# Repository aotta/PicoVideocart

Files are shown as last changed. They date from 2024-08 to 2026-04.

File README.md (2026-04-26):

# PicoVideocart

changelog: v.1.1 added with new Adafruit USB stack

Flash cart for SABA Videoplay - porting of 3DMaze PicoVideocart

This is a forked version of https://github.com/ZX-80/PicoVideocart (see original project for details) for using a cheaper and simpler pcb based on pico "Purple" clone and using its 16mb flash for storing games instead of the original SDCard

Since now it was only tested on SABA Videoplay (PAL), but it should work in Fairchild Channel-F (NTSC) too.

Thanks to my friend Dave, here's some more info and the label for the shell:
https://www.nightfallcrew.com/05/09/2024/flash-multicart-for-saba-videoplay-fairchild-channel-f/

**WARNING!** "purple" Pico has not the same pinout of original Raspberry "green" ones, you MUST use the clone or you may damage your hardware.

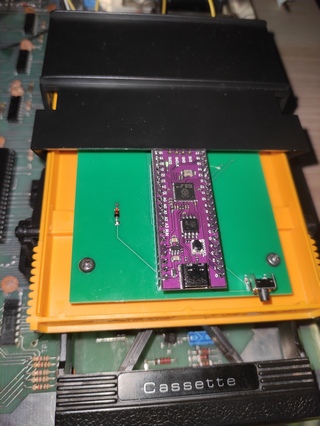
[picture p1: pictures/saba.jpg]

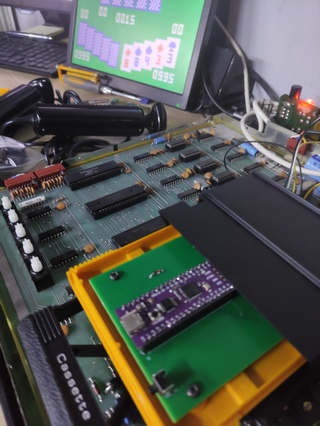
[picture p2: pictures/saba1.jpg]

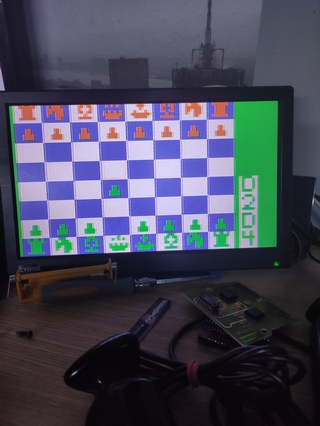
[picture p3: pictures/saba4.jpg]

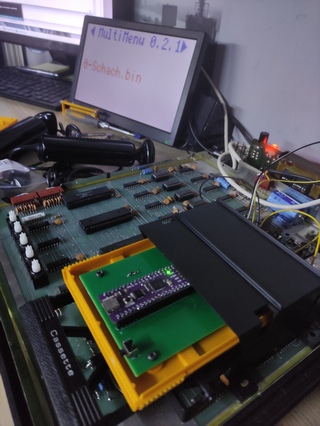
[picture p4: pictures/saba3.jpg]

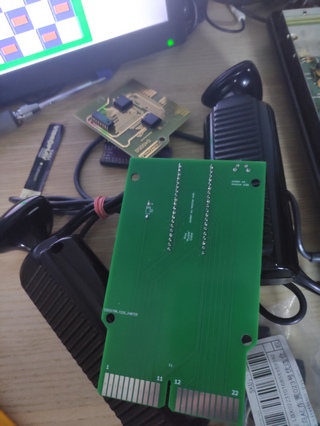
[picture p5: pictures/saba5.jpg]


Kicad project and gerbers files for the pcb are in the PCB folder, you need only a diode and a push buttons for resetting the cart if needed or want restart. 
Add you pico clone, and flash the firmware ".uf2" in the Pico by connecting it while pressing button on Pico and drop it in the opened windows on PC.

in V.1.0, "Bin" files should be added in flash using Arduino IDE plugin ( https://github.com/earlephilhower/arduino-littlefs-upload )
be sure to put boot.bin with other games, it's the menu selector.

**NOTE: V.1.1 use now Adafruit stack USB and you can upload bin files by connecting the card to a PC via usb cable and copying them on the flash folder. First time flash folder need to be formatted as FAT disk.
Now the multicart check at boot if it's inserted in console, if you get flashing led at boot, reset Picovideocart or powercycle the console until you get a steady flash led.

More info on AtariAge forum: https://forums.atariage.com/topic/274416-the-official-channel-f-thread/page/56/

Even if the diode should protect your console, **DO NOT CONNECT PICO WHILE INSERTED IN A POWERED ON CONSOLE!**

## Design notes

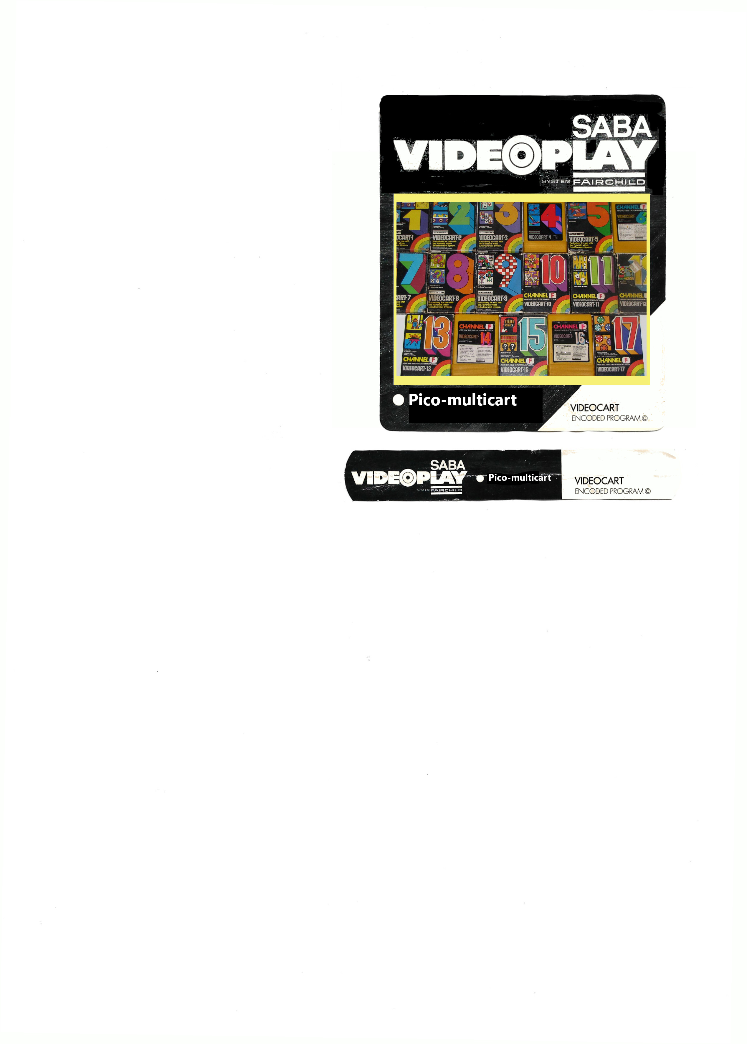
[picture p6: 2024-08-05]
pictures/ShellLabel.jpg

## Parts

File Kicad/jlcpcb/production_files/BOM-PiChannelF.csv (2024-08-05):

Comment | Designator | Footprint | LCSC
ChannelF Edge | E1 | ChannelF_EDGE
Diode | D1 | D_DO-35_SOD27_P7.62mm_Horizontal
Conn_01x20 | J1 | PinSocket_1x20_P2.54mm_Vertical
SW_Push | SW1 | SW_Tactile_SPST_Angled_PTS645Vx58-2LFS
Conn_01x20 | J2 | PinSocket_1x20_P2.54mm_Vertical
330 | R1 | R_Axial_DIN0207_L6.3mm_D2.5mm_P7.62mm_Horizontal
LED | D2 | LED_D3.0mm

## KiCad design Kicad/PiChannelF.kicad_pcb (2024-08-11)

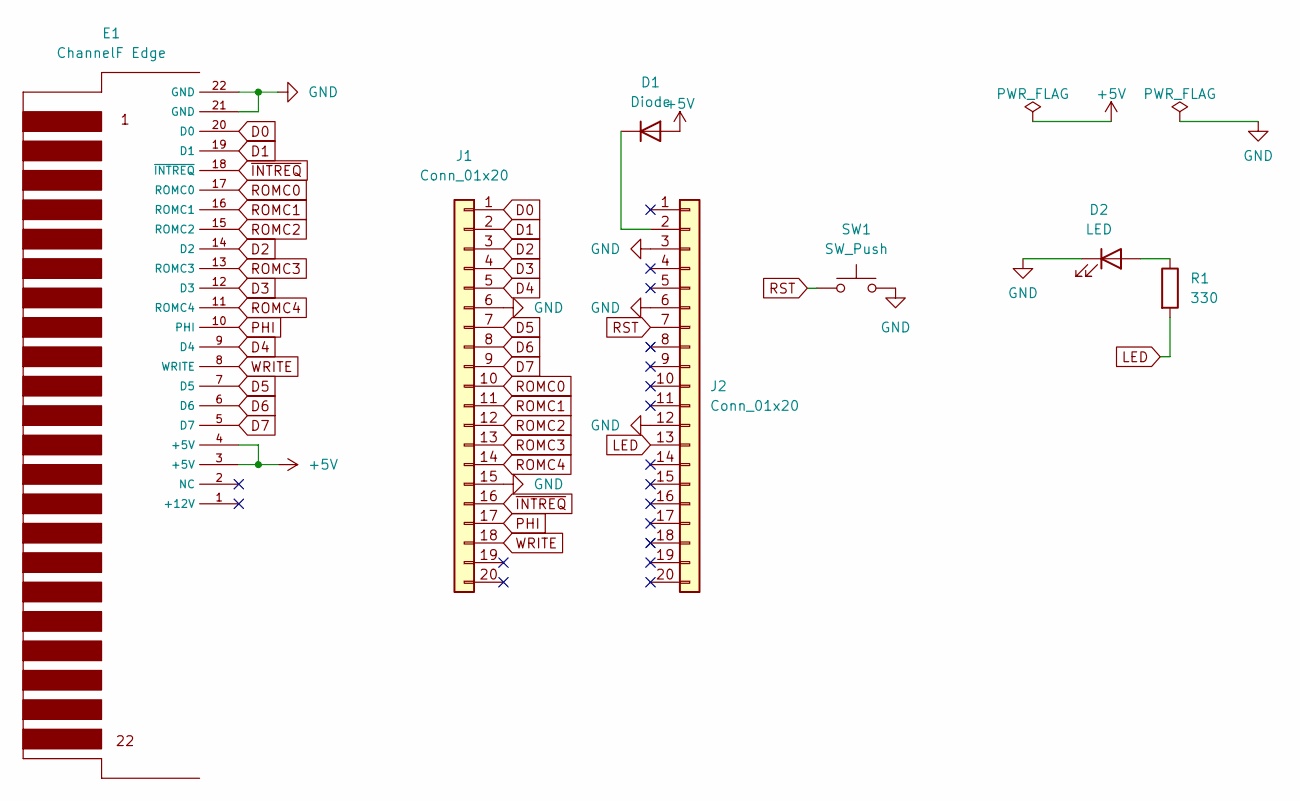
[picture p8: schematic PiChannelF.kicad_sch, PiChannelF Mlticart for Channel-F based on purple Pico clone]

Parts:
D1: Diode; D_DO-35_SOD27_P7.62mm_Horizontal
D2: LED; LED_D3.0mm
E1: ChannelF Edge; ChannelF_EDGE
J1, J2: Conn_01x20; PinSocket_1x20_P2.54mm_Vertical
R1: 330; R_Axial_DIN0207_L6.3mm_D2.5mm_P7.62mm_Horizontal
SW1: SW_Push; SW_Tactile_SPST_Angled_PTS645Vx58-2LFS

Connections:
+5V: D1.2 (A), E1.3 (+5V), E1.4 (+5V)
D0: E1.20 (D0), J1.1
D1: E1.19 (D1), J1.2
D2: E1.14 (D2), J1.3
D3: E1.12 (D3), J1.4
D4: E1.9 (D4), J1.5
D5: E1.7 (D5), J1.7
D6: E1.6 (D6), J1.8
D7: E1.5 (D7), J1.9
GND: D2.1 (K), E1.21 (GND), E1.22 (GND), J1.6, J1.15, J2.3, J2.6, J2.12, SW1.2
LED: J2.13, R1.2
unnamed: D1.1 (K), J2.2
unnamed: D2.2 (A), R1.1
PHI: E1.10 (PHI), J1.17
ROMC0: E1.17 (ROMC0), J1.10
ROMC1: E1.16 (ROMC1), J1.11
ROMC2: E1.15 (ROMC2), J1.12
ROMC3: E1.13 (ROMC3), J1.13
ROMC4: E1.11 (ROMC4), J1.14
RST: J2.7, SW1.1
WRITE: E1.8 (WRITE), J1.18
~INTREQ: E1.18 (~INTREQ), J1.16

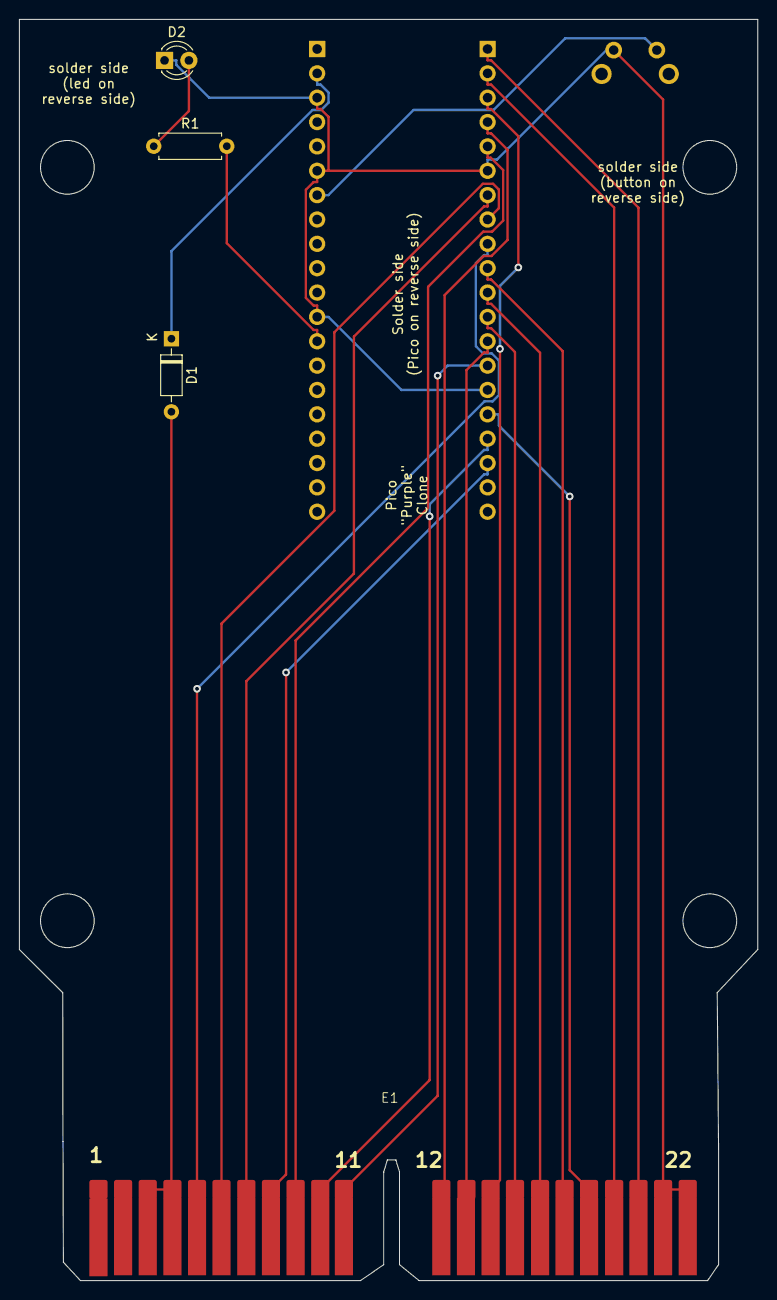
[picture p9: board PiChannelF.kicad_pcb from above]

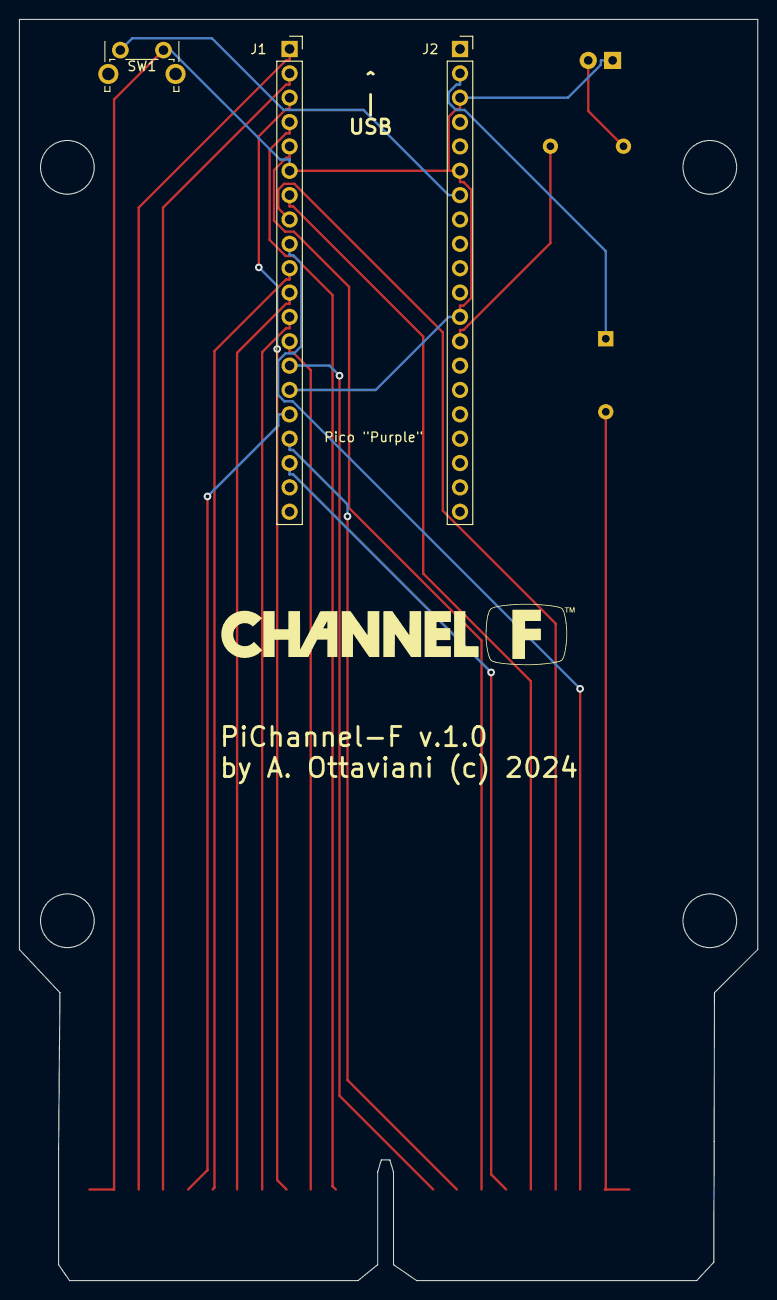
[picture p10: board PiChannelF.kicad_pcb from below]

Board: 2 copper layers, 77.0 x 131.5 mm, 7 parts (3 on the bottom side), 22 nets.

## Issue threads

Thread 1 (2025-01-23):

HD not recogniuing after flashing firmware and cartrdidge uf2

G7200, 2025-01-23:
Hi, I try to flash my Pico for the PicoVideocart. I followed your and Nightfallcrew's instructions and used Nightfallcrew's files for flashing the Pico. I flashed the cartridges first and then the firmware uf2 file as he told on his website. After that the Pico does not appear anymore on my PC via USB cable. Is that normal?
I have not understood yet how to put my own bin files to the Pico as I have no Arduino.
Thanks for your help!

aotta, 2025-01-23:
Yes it's normal, the only way for uploading rom filles is via the LittleFS plugin and Arduino IDE, follow instructions in the link in readme.md of this project

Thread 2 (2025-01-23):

Cart not recognized

G7200, 2025-01-23:
Hi,
I just did the Arduino part and compiled the firmware on the cart. After inserting the cart into my Saba Videoplay all I get is 3x4 red led flashes and after that always a non-flashing red light but nothing on the screen.
It is not very clear written what to flash first and how exactly. Normally the firmware is flashed by pushing the reset button and then the game files by just plugging in the USB without pushing reset on the pico.

aotta, 2025-01-23:
You MUST FIRST flash the pico with uf2 provided, THEN upload the bin file with littlefs upload.
It's clearly written in the readme.md:
`Add you pico clone, and flash the firmware ".uf2" in the Pico by connecting it while pressing button on Pico and drop it in the opened windows on PC. "Bin" files should be added in flash using Arduino IDE plugin ( https://github.com/earlephilhower/arduino-littlefs-upload )`

Please note that this section is for issue in the project, not a forum for discussing or user support.  You may use the mentioned thread in AtariAge forum for them.

G7200, 2025-01-24:
Hi Andrea,
Sorry for bothering you again.
The steps aren't really clear for me especially not for someone like me who
never used Arduino before.

I could now successfully upload the .bin files with the arduino
littlefs-upload plugin.

Is the firmware uf2 file you provided inside the arduino build folder from
your github?

Can this be flashed normally without arduino by just pressing the pico
button and copied over into the pico directory?

Thanks and all the best from Bern,
;) Balduin

Andrea Ottaviani ***@***.***> schrieb am Do., 23. Jan. 2025,
17:35:

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

aotta, 2025-01-24:
Hi Balduin, yes the steps are, strictly in this order:
1. Connect Pico to pc while pushing boot button
2. Flash Pico copying the uf2 file in build folder into the pico flash folder, as usual
3. Load games via littleFs plugin
4. Enjoy the carts

G7200, 2025-01-24:
Hi Andrea!
Thanks for replying again.
Are the two boot.bin (and old) files necessary and need to be in the data
folder?
For littlefs-upload I always use your PicoVideocart.ino sketch folder.

I hope I will get it working soon!

Thanks and all the best,
;) Balduin

Andrea Ottaviani ***@***.***> schrieb am Fr., 24. Jan. 2025,
13:53:

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

aotta, 2025-01-24:
Right, i missed mention but boot.bin must be uploaded with other games bin files.
You can use any sketch in background when using littlefs upload, but check that pico parameters are the right one, in particular the flash size must be set to 1mb/15 mb

G7200, 2025-01-24:
3. Step-Question: Do I need to press button on Pico to upload games via
littleFS plugin?
Because I cannot see the COM port after flashing the provided uf2 firmware
when pushing button on Pico.

All the best!

Am Fr., 24. Jan. 2025 um 13:53 Uhr schrieb Andrea Ottaviani <
***@***.***>:

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

Closed 2025-01-23.

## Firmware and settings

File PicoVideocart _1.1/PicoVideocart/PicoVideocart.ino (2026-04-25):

/* \file PicoVideocart.ino
 */
// V.1.1  moved from LittleFS to Adafruit USB Stack

#include "loader.hpp"
#include "error.hpp"
#include "romc.hpp"
#include "pico/stdlib.h"
#include "hardware/adc.h"
#include "hardware/flash.h"
#include "hardware/vreg.h"
#include "hardware/structs/bus_ctrl.h"
#include "SdFat_Adafruit_Fork.h"
#include "Adafruit_SPIFlash.h"
#include "Adafruit_TinyUSB.h"

Adafruit_FlashTransport_RP2040 flashTransport;
Adafruit_SPIFlash flash(&flashTransport);

FatVolume fatfs;
File32 root;
File32 file;
File32 romFile;

Adafruit_USBD_MSC usb_msc;
bool fs_formatted;
bool fs_changed = false;

// Pin definitions
#define D0_PIN     0
#define D1_PIN     1
#define D2_PIN     2
#define D3_PIN     3
#define D4_PIN     4
#define D5_PIN     5
#define D6_PIN     6
#define D7_PIN     7
#define ROMC0_PIN  8
#define ROMC1_PIN  9
#define ROMC2_PIN 10
#define ROMC3_PIN 11
#define ROMC4_PIN 12
#define INTREQ_PIN 13
#define PHI_PIN    14
#define WRITE_PIN  15

#define DATA_PIN_MASK   0x000000FFL
#define SET_DATA_MODE_OUT   gpio_set_dir_out_masked(DATA_PIN_MASK)
#define SET_DATA_MODE_IN    gpio_set_dir_in_masked(DATA_PIN_MASK)

// Callbacks USB MSC
int32_t msc_read_cb(uint32_t lba, void* buffer, uint32_t bufsize) {
  return flash.readBlocks(lba, (uint8_t*)buffer, bufsize / 512) ? bufsize : -1;
}

int32_t msc_write_cb(uint32_t lba, uint8_t* buffer, uint32_t bufsize) {
  return flash.writeBlocks(lba, buffer, bufsize / 512) ? bufsize : -1;
}

void msc_flush_cb(void) {
  flash.syncBlocks();
  fatfs.cacheClear();
  fs_changed = true;
}


void setup1() {
  bus_ctrl_hw->priority = BUSCTRL_BUS_PRIORITY_PROC1_BITS;
  
  for (int i = 0; i < 8; i++) {
    gpio_set_function(D0_PIN + i, GPIO_FUNC_SIO);
  }
  for (int i = 0; i < 5; i++) {
    gpio_set_function(ROMC0_PIN + i, GPIO_FUNC_SIO);
  }
  
  gpio_init(WRITE_PIN);
  gpio_set_dir(WRITE_PIN, GPIO_IN);
  gpio_init(PHI_PIN);
  gpio_set_dir(PHI_PIN, GPIO_IN);
  gpio_init(INTREQ_PIN);
  gpio_set_dir(INTREQ_PIN, GPIO_OUT);
  gpio_put(INTREQ_PIN, true);
  gpio_init(LED_BUILTIN);
  gpio_set_dir(LED_BUILTIN, GPIO_OUT);
  gpio_put(LED_BUILTIN, true);
}

void __not_in_flash_func(loop1)() {
  for (;;) {
    while(gpio_get(WRITE_PIN));
    SET_DATA_MODE_IN;
    while(gpio_get(WRITE_PIN) == 0);
    SET_DATA_MODE_IN;
    dbus = read_dbus();
    romc = read_romc();
    execute_romc();
  }
}

void setup() {
  
  
  // Verifica se siamo collegati alla console
  bool carton = false;
  int t = 100;
  
  while (gpio_get(PHI_PIN) == 0 && to_ms_since_boot(get_absolute_time()) < 2000) {
    if (to_ms_since_boot(get_absolute_time()) > t) {
      t += 100;
    }
    sleep_ms(1);
  }
  
 if (gpio_get(PHI_PIN) == 1) {
    carton = true;  
 }
  
  // Inizializza flash
  flash.begin();
  
  // Configura USB MSC
  usb_msc.setID("PicoVideocart", "External Flash", "1.0");
  usb_msc.setReadWriteCallback(msc_read_cb, msc_write_cb, msc_flush_cb);
  usb_msc.setCapacity(flash.size() / 512, 512);
  usb_msc.setUnitReady(true);
  usb_msc.begin();
  
  if (TinyUSBDevice.mounted()) {
    TinyUSBDevice.detach();
    sleep_ms(10);
    TinyUSBDevice.attach();
    sleep_ms(10);
  }
  
  // Monta filesystem
  fs_formatted = fatfs.begin(&flash);
  
  if (!carton) {
    // Modalità PC
    usb_msc.setUnitReady(true);
    while (1) {
      blink_code(1);
    }
  }
  
  // === MODALITÀ CONSOLE ===
  usb_msc.setUnitReady(false);
  
  
  // === SCANSIONE FILE ===
  uint16_t file_counter = 0;
  
  if (root.open("/", O_RDONLY)) {
    while (file_counter < FOLDER_LIMIT) {
      if (!file.openNext(&root, O_RDONLY)) break;
      
      if (!file.isDir()) {
        char filename[256];
        file.getName(filename, sizeof(filename));
        
        // Verifica estensione .bin o .chf
        int len = strlen(filename);
        bool is_valid = false;
        
        if (len > 4) {
          if (strcmp(filename + len - 4, ".bin") == 0) {
            is_valid = true;
          } else if (strcmp(filename + len - 4, ".chf") == 0) {
            is_valid = true;
          }
        }
        
        if (is_valid) {
          file_data[file_counter].isFile = true;
          file_data[file_counter].title[0] = ' ';
          
          // Copia il nome senza estensione
          char display_name[32];
          strncpy(display_name, filename, 31);
          if (len > 4 && strcmp(filename + len - 4, ".bin") == 0) {
            display_name[len - 4] = '\0';
          }
          strncpy((char*)file_data[file_counter].title + 1, display_name, 30);
          file_data[file_counter].title[31] = '\0';
          
          file_counter++;
        }
      }
      file.close();
    }
    root.close();
  }
  
  DIR_LIMIT = file_counter;
  
  // === SEGNALA QUANTI FILE SONO STATI TROVATI ===
  // Lampeggia il numero di file trovati (es: 3 file = 3 lampeggi)
  if (DIR_LIMIT == 0) {
    // Nessun file trovato: lampeggio rapido continuo
    blink_code(BLINK::NO_VALID_FILES, 5);
  }
  
  // Scrivi il primo titolo nella RAM
  if (DIR_LIMIT > 0) {
    strncpy((char*)program_rom + SRAM_START_ADDR + 2, 
            file_data[0].title, 30);
  } else {
    const char* no_data = "No Data";
    for (int i = 0; i < 8; i++) {
      program_rom[SRAM_START_ADDR + 2 + i] = no_data[i];
    }
  }
  //File32 romFile;
  // === CARICA BOOT.BIN ===
  romFile = fatfs.open("/boot.bin", O_RDONLY);
  if (!romFile) {
    romFile = fatfs.open("/boot_old.bin", O_RDONLY);
  }
  
  // Carica il boot (lampeggio durante il caricamento)
  load_game(romFile);
  
  // Overclock
  vreg_set_voltage(VREG_VOLTAGE_1_30);
  sleep_ms(1);
  if (!set_sys_clock_khz(360000, false)) {
    blink_code(BLINK::OVERCLOCK_FAILED, 2);
    set_sys_clock_khz(300000, false);
  }
  
  // LED acceso fisso = tutto OK
  gpio_put(LED_BUILTIN, true);
}

void loop() {
  sleep_ms(100);
  
  if (load_new_game_trigger) {
    load_new_game_trigger = false;
    
    // Lampeggio rapido durante il caricamento
    gpio_put(LED_BUILTIN, false);
    
    while (pc0 >= 0x800) {
      sleep_ms(1);
    }
    
    uint16_t file_index = static_cast<Launcher*>(IOPorts[0xFF])->file_index;
    
    if (file_index < DIR_LIMIT) {
      char filename[32];
      strcpy(filename, file_data[file_index].title);
      filename[0] = '/';
      // Ricostruisci il nome completo con estensione
      strcat(filename, ".bin");
      //File32 romFile;
      romFile = fatfs.open(filename, O_RDONLY);
      if (romFile) {
        load_game(romFile);
        
        if (!set_sys_clock_khz(400000, false)) {
          set_sys_clock_khz(300000, false);
        }
      }
    }
    
    gpio_put(LED_BUILTIN, true);
  }
}

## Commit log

2024-08-11 Add files via upload
    little shift and enlarge of holes for screw in pcb
    [PiChannelF-CuBottom.gbr, PiChannelF-CuTop.gbr, PiChannelF-EdgeCuts.gbr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]
2024-08-13 Add files via upload
    added "thinking" led in Schach Saba cart

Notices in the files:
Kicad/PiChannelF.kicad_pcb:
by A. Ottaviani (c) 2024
